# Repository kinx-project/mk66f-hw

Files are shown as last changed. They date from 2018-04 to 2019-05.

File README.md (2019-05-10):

This repository contains the hardware design files for the kinX mk66f keyboard
controller, a replacement controller for the Kinesis Advantage keyboard.

You can order this PCB at [OSH Park](https://oshpark.com/shared_projects/75qdnpC4).

You can order the components at [Mouser](https://www.mouser.ch/ProjectManager/ProjectDetail.aspx?AccessID=a9afbb88bc)

Note that the bootloader chip `IC_MKL04Z32_TQFP32` is not included in the BOM
and is only available from PJRC’s shop: https://www.pjrc.com/store/ic_mkl02.html

Also note that micro USB cables are not included in the BOM (you’ll need one for
power and firmware flashing, another one for USBHS data). I recommend building
the kinX hub, whose BOM includes the USB cables and which is a drop-in
replacement for the hub that comes in the Kinesis Advantage keyboard:
https://github.com/kinx-project/hub-hw

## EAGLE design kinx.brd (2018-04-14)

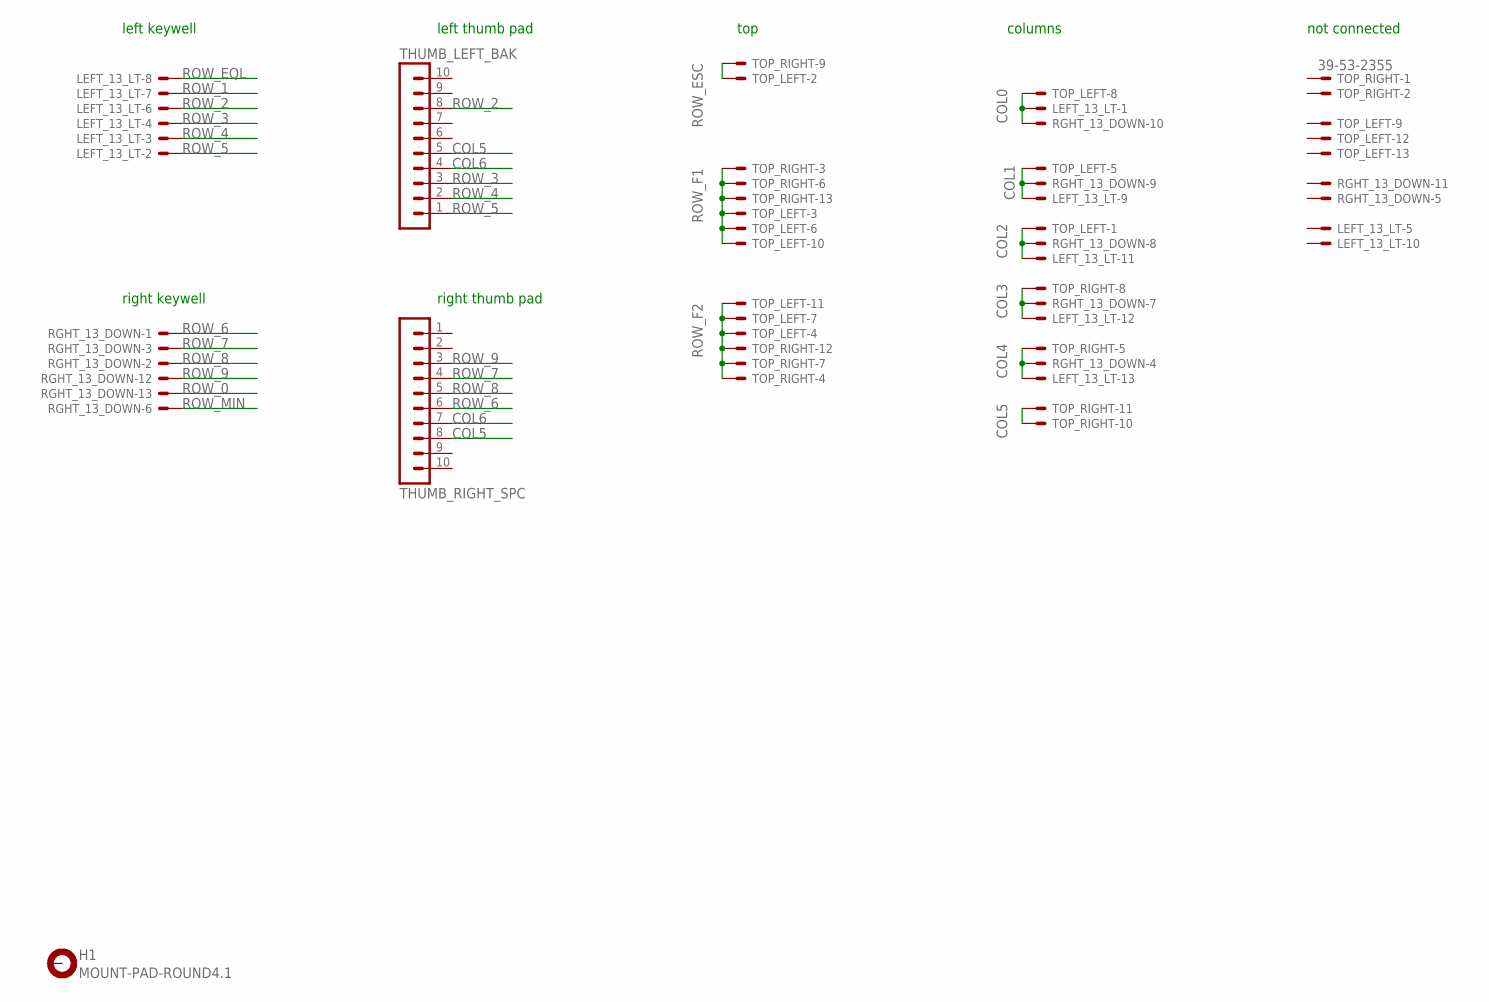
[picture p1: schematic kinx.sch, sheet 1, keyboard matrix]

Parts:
H1: MOUNT-PAD-ROUND4.1; 4,1-PAD
LEFT_13_LT: 39-53-2355; 39-53-2135; DIGIKEY WM14526-ND
RGHT_13_DOWN: 39-53-2355; 39-53-2135; DIGIKEY WM14526-ND
THUMB_LEFT_BAK: MA10-1
THUMB_RIGHT_SPC: MA10-1
TOP_LEFT: 39-53-2355; 39-53-2135; DIGIKEY WM14526-ND
TOP_RIGHT: 39-53-2355; 39-53-2135; DIGIKEY WM14526-ND

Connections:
COL0: LEFT_13_LT.P$1, RGHT_13_DOWN.P$10, TOP_LEFT.P$8; also elsewhere on the board
COL1: LEFT_13_LT.P$9, RGHT_13_DOWN.P$9, TOP_LEFT.P$5; also elsewhere on the board
COL2: LEFT_13_LT.P$11, RGHT_13_DOWN.P$8, TOP_LEFT.P$1; also elsewhere on the board
COL3: LEFT_13_LT.P$12, RGHT_13_DOWN.P$7, TOP_RIGHT.P$8; also elsewhere on the board
COL4: LEFT_13_LT.P$13, RGHT_13_DOWN.P$4, TOP_RIGHT.P$5; also elsewhere on the board
COL5: THUMB_LEFT_BAK.5, THUMB_RIGHT_SPC.8, TOP_RIGHT.P$10, TOP_RIGHT.P$11; also elsewhere on the board
COL6: THUMB_LEFT_BAK.4, THUMB_RIGHT_SPC.7; also elsewhere on the board
ROW_0: RGHT_13_DOWN.P$13; also elsewhere on the board
ROW_1: LEFT_13_LT.P$7; also elsewhere on the board
ROW_2: LEFT_13_LT.P$6, THUMB_LEFT_BAK.8; also elsewhere on the board
ROW_3: LEFT_13_LT.P$4, THUMB_LEFT_BAK.3; also elsewhere on the board
ROW_4: LEFT_13_LT.P$3, THUMB_LEFT_BAK.2; also elsewhere on the board
ROW_5: LEFT_13_LT.P$2, THUMB_LEFT_BAK.1; also elsewhere on the board
ROW_6: RGHT_13_DOWN.P$1, THUMB_RIGHT_SPC.6; also elsewhere on the board
ROW_7: RGHT_13_DOWN.P$3, THUMB_RIGHT_SPC.4; also elsewhere on the board
ROW_8: RGHT_13_DOWN.P$2, THUMB_RIGHT_SPC.5; also elsewhere on the board
ROW_9: RGHT_13_DOWN.P$12, THUMB_RIGHT_SPC.3; also elsewhere on the board
ROW_EQL: LEFT_13_LT.P$8; also elsewhere on the board
ROW_ESC: TOP_LEFT.P$2, TOP_RIGHT.P$9; also elsewhere on the board
ROW_F1: TOP_LEFT.P$3, TOP_LEFT.P$6, TOP_LEFT.P$10, TOP_RIGHT.P$3, TOP_RIGHT.P$6, TOP_RIGHT.P$13; also elsewhere on the board
ROW_F2: TOP_LEFT.P$4, TOP_LEFT.P$7, TOP_LEFT.P$11, TOP_RIGHT.P$4, TOP_RIGHT.P$7, TOP_RIGHT.P$12; also elsewhere on the board
ROW_MIN: RGHT_13_DOWN.P$6; also elsewhere on the board

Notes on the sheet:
left keywell
right keywell
left thumb pad
right thumb pad
columns
not connected
top

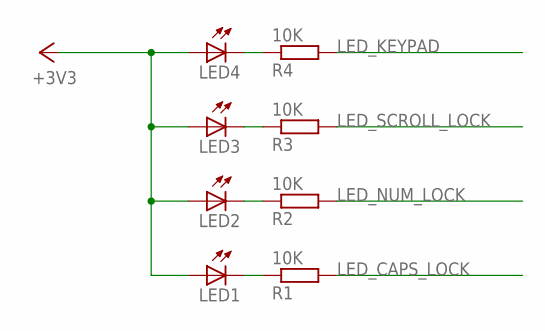
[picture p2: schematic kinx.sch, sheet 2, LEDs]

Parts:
LED1, LED2, LED3, LED4: LEDSML1206; SML1206
R1, R2, R3, R4: 10K; R1206

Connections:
+3V3: LED1.A, LED2.A, LED3.A, LED4.A; also elsewhere on the board
LED_CAPS_LOCK: R1.2; also elsewhere on the board
LED_KEYPAD: R4.2; also elsewhere on the board
LED_NUM_LOCK: R2.2; also elsewhere on the board
LED_SCROLL_LOCK: R3.2; also elsewhere on the board
unnamed: LED4.C, R4.1
unnamed: LED3.C, R3.1
unnamed: LED2.C, R2.1
unnamed: LED1.C, R1.1

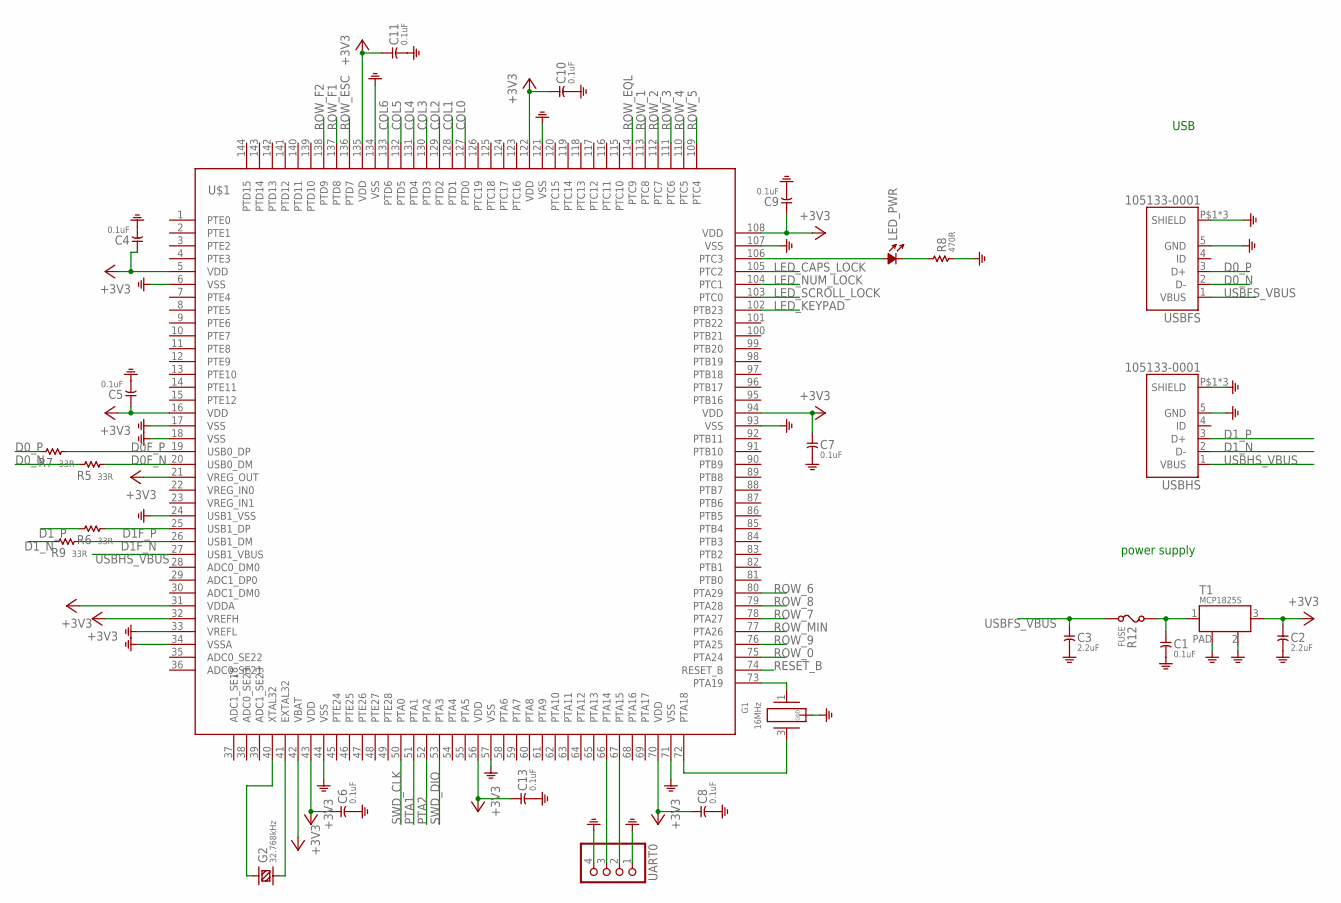
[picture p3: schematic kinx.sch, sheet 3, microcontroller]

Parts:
C1, C4, C5, C6, C7, C8, C9, C10, C11, C13: 0.1uF; C0603
C2, C3: 2.2uF; C0805
G1: 16MHz; FHXXX; DIGIKEY SER4068CT-ND
G2: 32.768kHz; TC26H
LED_PWR: LED; LED-0805
R5, R6, R7, R9: 33R; R0603
R8: 470R; R0603
R12: FUSE; F0805; DIGIKEY 507-1813-1-ND
T1: MCP1825S; SOT-223; DIGIKEY MCP1825S-3302E/DB-ND
U$1: MK66FX1M0VLQ18; TQFP144; DIGIKEY 568-13334-ND
UART0: PINHD-1X4/90; 1X04/90
USBFS: 105133-0001; MOLEX_105133-0001; DIGIKEY WM10134CT-ND
USBHS: 105133-0001; MOLEX_105133-0001; DIGIKEY WM10134CT-ND

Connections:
+3V3: C2.1, C4.1, C5.1, C6.1, C7.1, C8.1, C9.1, C10.1, C11.1, C13.1, T1.3 (OUT), U$1.5 (VDD), U$1.16 (VDD), U$1.21 (VREG_OUT), U$1.31 (VDDA), U$1.32 (VREFH), U$1.42 (VBAT), U$1.43 (VDD), U$1.56 (VDD), U$1.70 (VDD), U$1.94 (VDD), U$1.108 (VDD), U$1.122 (VDD), U$1.135 (VDD); also elsewhere on the board
COL0: U$1.127 (PTD0); also elsewhere on the board
COL1: U$1.128 (PTD1); also elsewhere on the board
COL2: U$1.129 (PTD2); also elsewhere on the board
COL3: U$1.130 (PTD3); also elsewhere on the board
COL4: U$1.131 (PTD4); also elsewhere on the board
COL5: U$1.132 (PTD5); also elsewhere on the board
COL6: U$1.133 (PTD6); also elsewhere on the board
D0F_N: R5.2, U$1.20 (USB0_DM)
D0F_P: R7.2, U$1.19 (USB0_DP)
D0_N: R5.1, USBFS.2 (D-)
D0_P: R7.1, USBFS.3 (D+)
D1F_N: R9.2, U$1.26 (USB1_DM)
D1F_P: R6.2, U$1.25 (USB1_DP)
D1_N: R9.1, USBHS.2 (D-)
D1_P: R6.1, USBHS.3 (D+)
GND: C1.2, C2.2, C3.2, C4.2, C5.2, C6.2, C7.2, C8.2, C9.2, C10.2, C11.2, C13.2, G1.2 (GND), G1.4 (GND), R8.1, T1.2 (GND), T1.PAD, U$1.6 (VSS), U$1.17 (VSS), U$1.18 (VSS), U$1.24 (USB1_VSS), U$1.33 (VREFL), U$1.34 (VSSA), U$1.44 (VSS), U$1.57 (VSS), U$1.71 (VSS), U$1.93 (VSS), U$1.107 (VSS), U$1.121 (VSS), U$1.134 (VSS), UART0.1, UART0.4, USBFS.5 (GND), USBFS.P$1 (SHIELD), USBFS.P$2 (SHIELD), USBFS.P$3 (SHIELD), USBHS.5 (GND), USBHS.P$1 (SHIELD), USBHS.P$2 (SHIELD), USBHS.P$3 (SHIELD); also elsewhere on the board
LED_CAPS_LOCK: U$1.105 (PTC2); also elsewhere on the board
LED_KEYPAD: U$1.102 (PTB23); also elsewhere on the board
LED_NUM_LOCK: U$1.104 (PTC1); also elsewhere on the board
LED_SCROLL_LOCK: U$1.103 (PTC0); also elsewhere on the board
unnamed: C1.1, R12.2, T1.1 (IN)
unnamed: G1.1, U$1.73 (PTA19)
unnamed: G1.3 (2), U$1.72 (PTA18)
unnamed: G2.2 (1), U$1.40 (XTAL32)
unnamed: G2.1 (2), U$1.41 (EXTAL32)
unnamed: LED_PWR.+, U$1.106 (PTC3)
unnamed: LED_PWR.-, R8.2
PTA1: U$1.51 (PTA1); also elsewhere on the board
PTA2: U$1.52 (PTA2); also elsewhere on the board
RESET_B: U$1.74 (RESET_B); also elsewhere on the board
ROW_0: U$1.75 (PTA24); also elsewhere on the board
ROW_1: U$1.113 (PTC8); also elsewhere on the board
ROW_2: U$1.112 (PTC7); also elsewhere on the board
ROW_3: U$1.111 (PTC6); also elsewhere on the board
ROW_4: U$1.110 (PTC5); also elsewhere on the board
ROW_5: U$1.109 (PTC4); also elsewhere on the board
ROW_6: U$1.80 (PTA29); also elsewhere on the board
ROW_7: U$1.78 (PTA27); also elsewhere on the board
ROW_8: U$1.79 (PTA28); also elsewhere on the board
ROW_9: U$1.76 (PTA25); also elsewhere on the board
ROW_EQL: U$1.114 (PTC9); also elsewhere on the board
ROW_ESC: U$1.136 (PTD7); also elsewhere on the board
ROW_F1: U$1.137 (PTD8); also elsewhere on the board
ROW_F2: U$1.138 (PTD9); also elsewhere on the board
ROW_MIN: U$1.77 (PTA26); also elsewhere on the board
RX: U$1.67 (PTA15), UART0.2
SWD_CLK: U$1.50 (PTA0); also elsewhere on the board
SWD_DIO: U$1.53 (PTA3); also elsewhere on the board
TX: U$1.66 (PTA14), UART0.3
USBFS_VBUS: C3.1, R12.1, USBFS.1 (VBUS)
USBHS_VBUS: U$1.27 (USB1_VBUS), USBHS.1 (VBUS)
VREG_IN0: U$1.22 (VREG_IN0)
VREG_IN1: U$1.23 (VREG_IN1)

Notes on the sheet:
USB
power supply

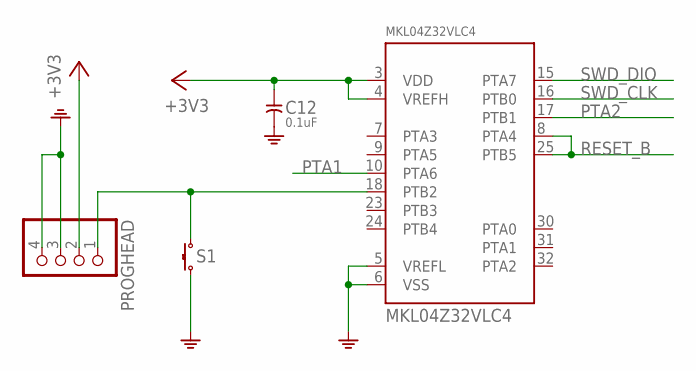
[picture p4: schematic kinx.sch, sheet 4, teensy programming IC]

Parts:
C12: 0.1uF; C0603
MKL04Z32VLC4: MKL04Z32VLC4; LQFP32-08
PROGHEAD: PINHD-1X4/90; 1X04/90
S1: TACT_SWITCH; ALPS_SKHH

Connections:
+3V3: C12.1, MKL04Z32VLC4.3 (VDD), MKL04Z32VLC4.4 (VREFH), PROGHEAD.2; also elsewhere on the board
GND: C12.2, MKL04Z32VLC4.5 (VREFL), MKL04Z32VLC4.6 (VSS), PROGHEAD.3, PROGHEAD.4, S1.3, S1.4 (3); also elsewhere on the board
unnamed: MKL04Z32VLC4.18 (PTB2), PROGHEAD.1, S1.1, S1.2 (1)
PTA1: MKL04Z32VLC4.10 (PTA6); also elsewhere on the board
PTA2: MKL04Z32VLC4.17 (PTB1); also elsewhere on the board
RESET_B: MKL04Z32VLC4.8 (PTA4), MKL04Z32VLC4.25 (PTB5); also elsewhere on the board
SWD_CLK: MKL04Z32VLC4.16 (PTB0); also elsewhere on the board
SWD_DIO: MKL04Z32VLC4.15 (PTA7); also elsewhere on the board

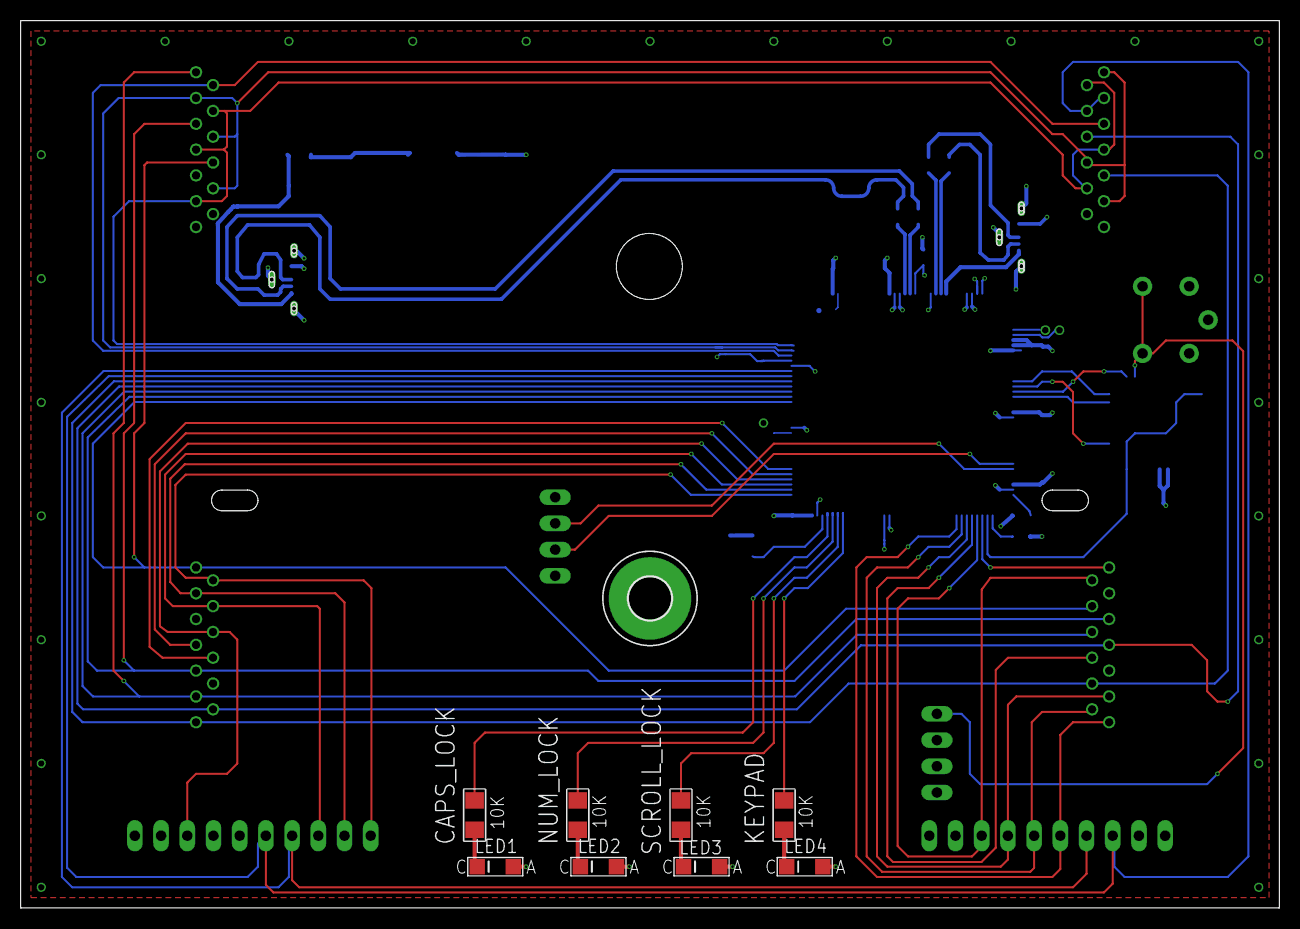
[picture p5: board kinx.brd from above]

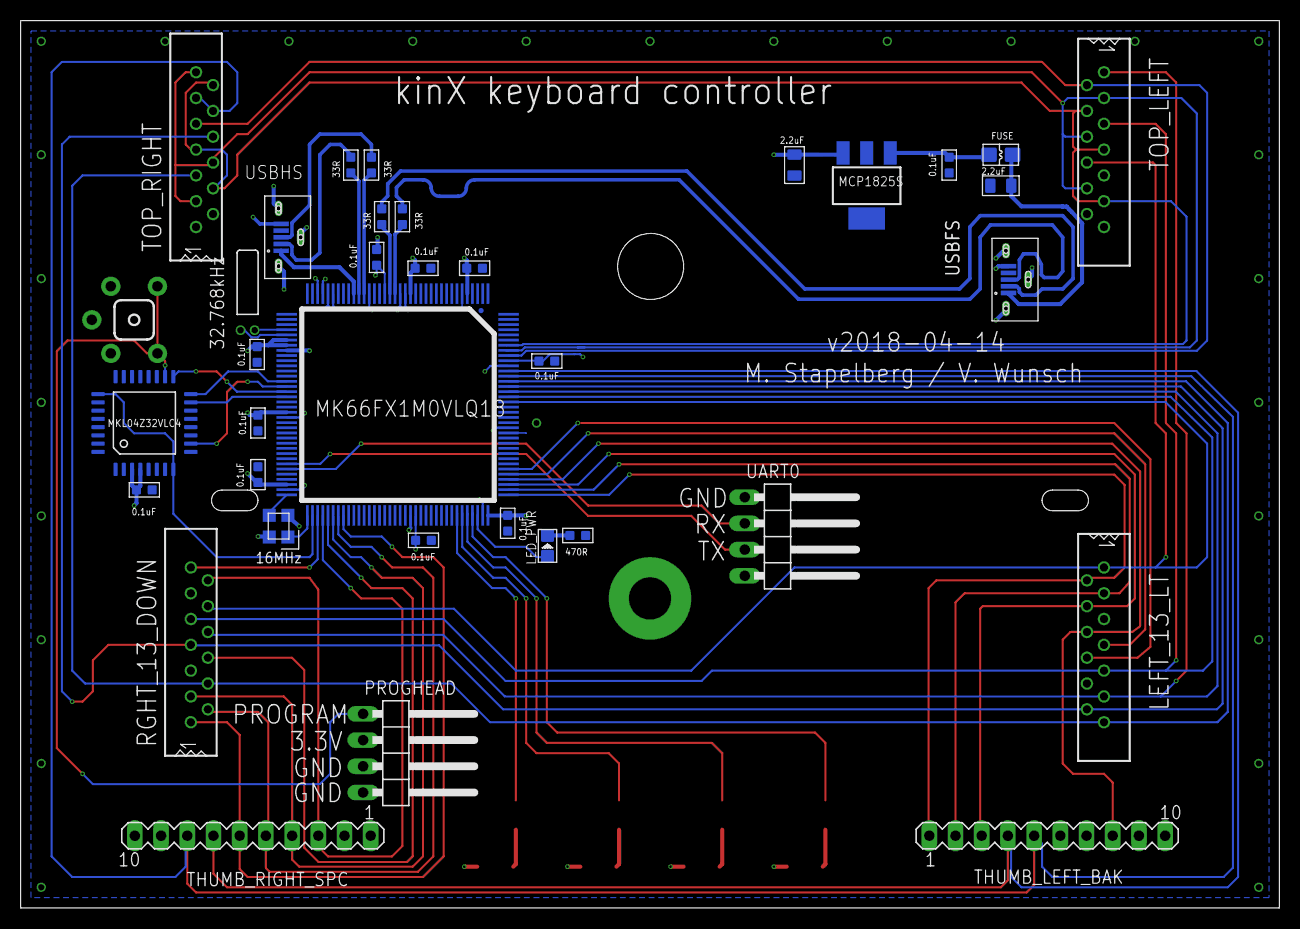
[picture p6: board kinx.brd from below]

Board: 4 copper layers, 122.0 x 86.0 mm, 45 parts (36 on the bottom side), 57 nets.

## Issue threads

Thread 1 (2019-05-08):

Mouser BOM misses R1-R4 (10k 1206 resistors)

fd0, 2019-05-08:
Hey, I just noticed that the BOM linked for Mouser misses the resistors R1-R4, 10k 1206. Is that intentional? :)

stapelberg, 2019-05-08:
Thanks for reporting this! I’ll fix it later today. No intention here :)

stapelberg, 2019-05-09:
Just got a chance to take a look at this.

https://github.com/kinx-project/mk66f-hw/blob/9843ece854f8d0d39c7284b8e975a7eaf654a99e/bom.mouser.csv#L17 are the resistors, see https://www.mouser.ch/ProductDetail/Yageo/RC1206FR-0710KL?qs=%252BhB4WxZmbVEJV82xdVgRUw==

Did you miss that line, or was there an issue with importing the CSV file somewhere?

stapelberg, 2019-05-09:
> btw, here's a [CSV](https://gist.github.com/ab9dd47c5fb4b62c508c8dad4bdded72) with most of the parts for Digikey, I'm not sure how useful that is for other people though. Some parts I had already orderer from elsewhere, most part numbers from the Mouser list can directly be used to find the parts on Digikey.

Just to be 100% clear: is that BOM complete (you mentioned you have ordered some parts elsewhere)? If yes, could you send it in a PR please? It’s certainly nice to have a BOM for digikey :)

fd0, 2019-05-09:
> Did you miss that line, or was there an issue with importing the CSV file somewhere?

Ah, maybe my description was misleading (sorry for that): the resistors are missing from the linked project basket at Mouser, here: https://www.mouser.ch/ProjectManager/ProjectDetail.aspx?AccessID=7798be8d00

That's the one I used for placing an order at Digikey. I'll revisit this issue once the parts arrive, then I know if something is missing ;)

stapelberg, 2019-05-10:
Thanks for clarifying. I have updated the cart (it has a new link now).

Closed 2019-05-10.

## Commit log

2018-03-27 fix silkscreen for power LED
    [kinx.brd, kinx.sch]
2018-03-27 use 10K resistors to drive the LEDs
    [kinx.brd, kinx.sch]
2018-03-27 put LED resistor value on the silkscreen
    [kinx.brd]
2018-03-27 Switch USB connector from Würth (1.0mm PCB) to Molex (1.5mm PCB)
    The Würth ones are incompatible with our PCB thickness — they can just barely be
    soldered, and are loose after just a few connections.
    [kinx.brd, kinx.sch]
2018-03-27 fix the molex connector library from snapeda
    [kinx.brd, kinx.sch]
2018-03-27 route the new USB connectors, rotate so that angled cables fit
    [kinx.brd]
2018-03-27 fix silkscreen for 0.1μF capacitor
    [kinx.brd]
2018-03-27 Enlarge crystal pads for easier soldering
    [kinx.brd, kinx.sch]
2018-03-27 Move vias for easier soldering
    [kinx.brd]
2018-03-27 Connect remaining VSS pins
    [kinx.brd, kinx.sch]
2018-03-27 move via for clearance
    [kinx.brd]
2018-03-27 Fix Molex connector pads
    As per the PCB layout from the drawing:
    http://www.molex.com/pdm_docs/sd/1051330001_sd.pdf
    [kinx.brd, kinx.sch]
2018-03-27 fix silk screen for USB ports
    [kinx.brd]
2018-03-27 Add MK66FX1M0VLQ18-based kinX controller version
    [kinx.brd, kinx.sch]
2018-03-27 silk screen: crystal: make orientation label visible again after pad enlargement
    [kinx.brd, kinx.sch]
2018-03-27 fix MPN/OC_MOUSER for the molex 105133-0011 connectors
    [kinx.brd, kinx.sch]
2018-03-27 silk screen: add resistor outlines on top layer
    [kinx.brd, kinx.sch]
2018-03-27 add LED resistor order codes
    [kinx.brd]
2018-03-27 silk screen: very very clearly mark LED cathode/anode
    [kinx.brd, kinx.sch]
2018-03-27 Bugfix: wire up USB1_VBUS and all GND airwires
    [kinx.brd, kinx.sch]
2018-03-27 Clean up schematic (no board changes)
    [kinx.sch]
2018-03-27 enlarge FUSE pads for easier soldering
    [kinx.brd, kinx.sch]
2018-03-27 approve all remaining DRC errors, this is the best we can do
    [kinx.brd]
2018-03-27 better net names
    [kinx.brd, kinx.sch]
2018-03-27 enlarge LED pads for easier soldering
    [kinx.brd, kinx.sch]
2018-03-27 update version on silkscreen
    [kinx.brd]
2018-03-27 fix ERC errors and approve okay errors
    [kinx.sch]
2018-03-27 bump revision to v2018-02-11
    [kinx.brd]
2018-03-27 Switch to Molex 105133-0011 (USB 2.0 instead of USB)
    [kinx.brd, kinx.sch]
2018-04-14 Increase isolation of GND planes for better manufacturability
    Done using “change isolate 8mil” on both GND planes.
    A few previous PCBs had their ground plane accidentally connected to traces.
    OSH Park explained that this can be due to imbalances in the acid concentration,
    and advised to increase isolation.
    [kinx.brd]
2018-04-14 bump revision to v2018-04-14
    [kinx.brd]
2018-04-14 add mouser part number for the 10K resistors
    [kinx.sch]
2018-04-14 Change 0.1μF capacitors from 81-GRM39X104K16 to 80-C0603C104M4R7411
    The former is no longer available.
    [kinx.brd, kinx.sch]
2018-04-14 add BOM to git
    [bom.mouser.csv]
2018-04-14 add note about the bootloader chip and USB cables
2019-05-10 update mouser cart to contain resistors, replace out-of-stock components
    fixes #1
